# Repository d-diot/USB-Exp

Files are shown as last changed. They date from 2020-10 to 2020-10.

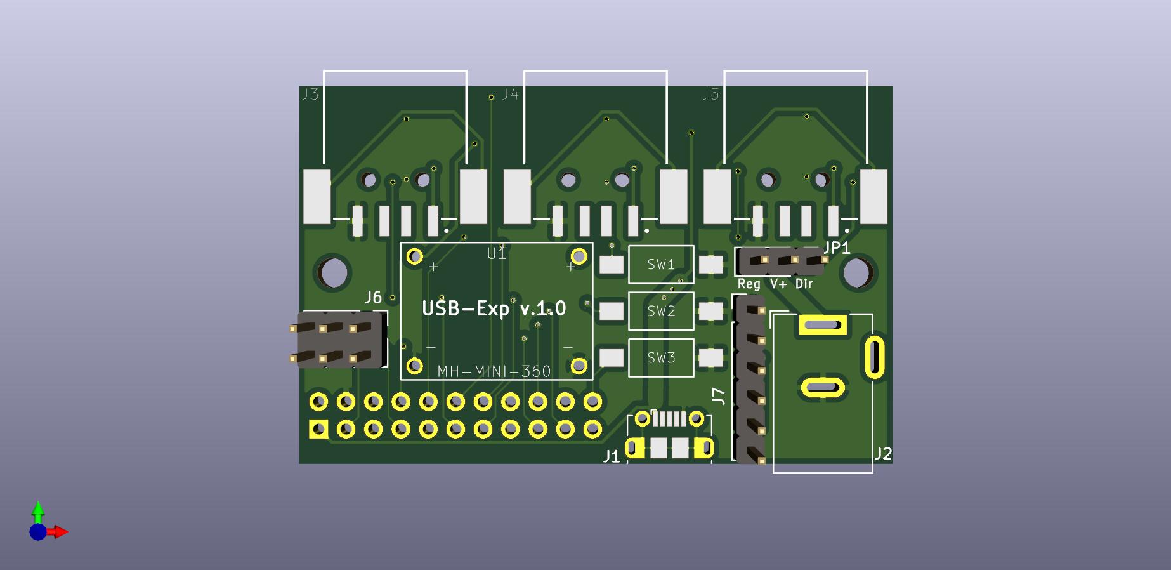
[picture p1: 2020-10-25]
export/images/1-USB-Exp-front.jpg

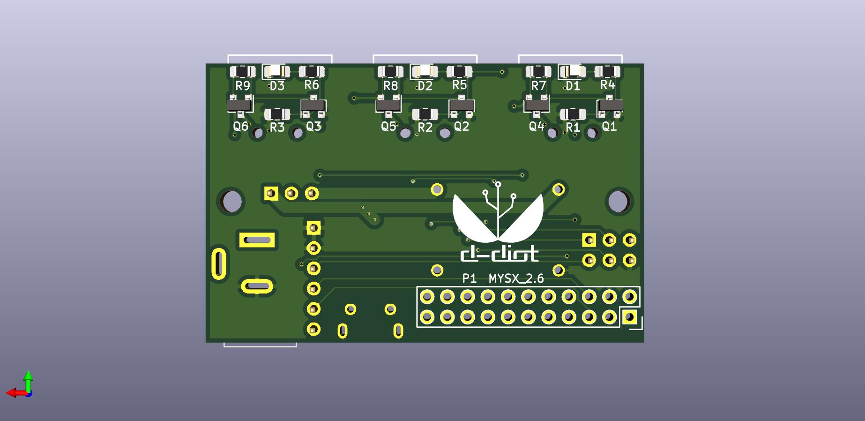
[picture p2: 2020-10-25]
export/images/2-USB-Exp-rear.jpg

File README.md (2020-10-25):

# USB-Exp

This board is part of the [d-diot project](https://www.d-diot.com)
See the dedicated [wiki page](https://wiki.d-diot.com/hardware/pcb/mysensors/usb-exp) to know more about this board.

pcbfront

pcbrear

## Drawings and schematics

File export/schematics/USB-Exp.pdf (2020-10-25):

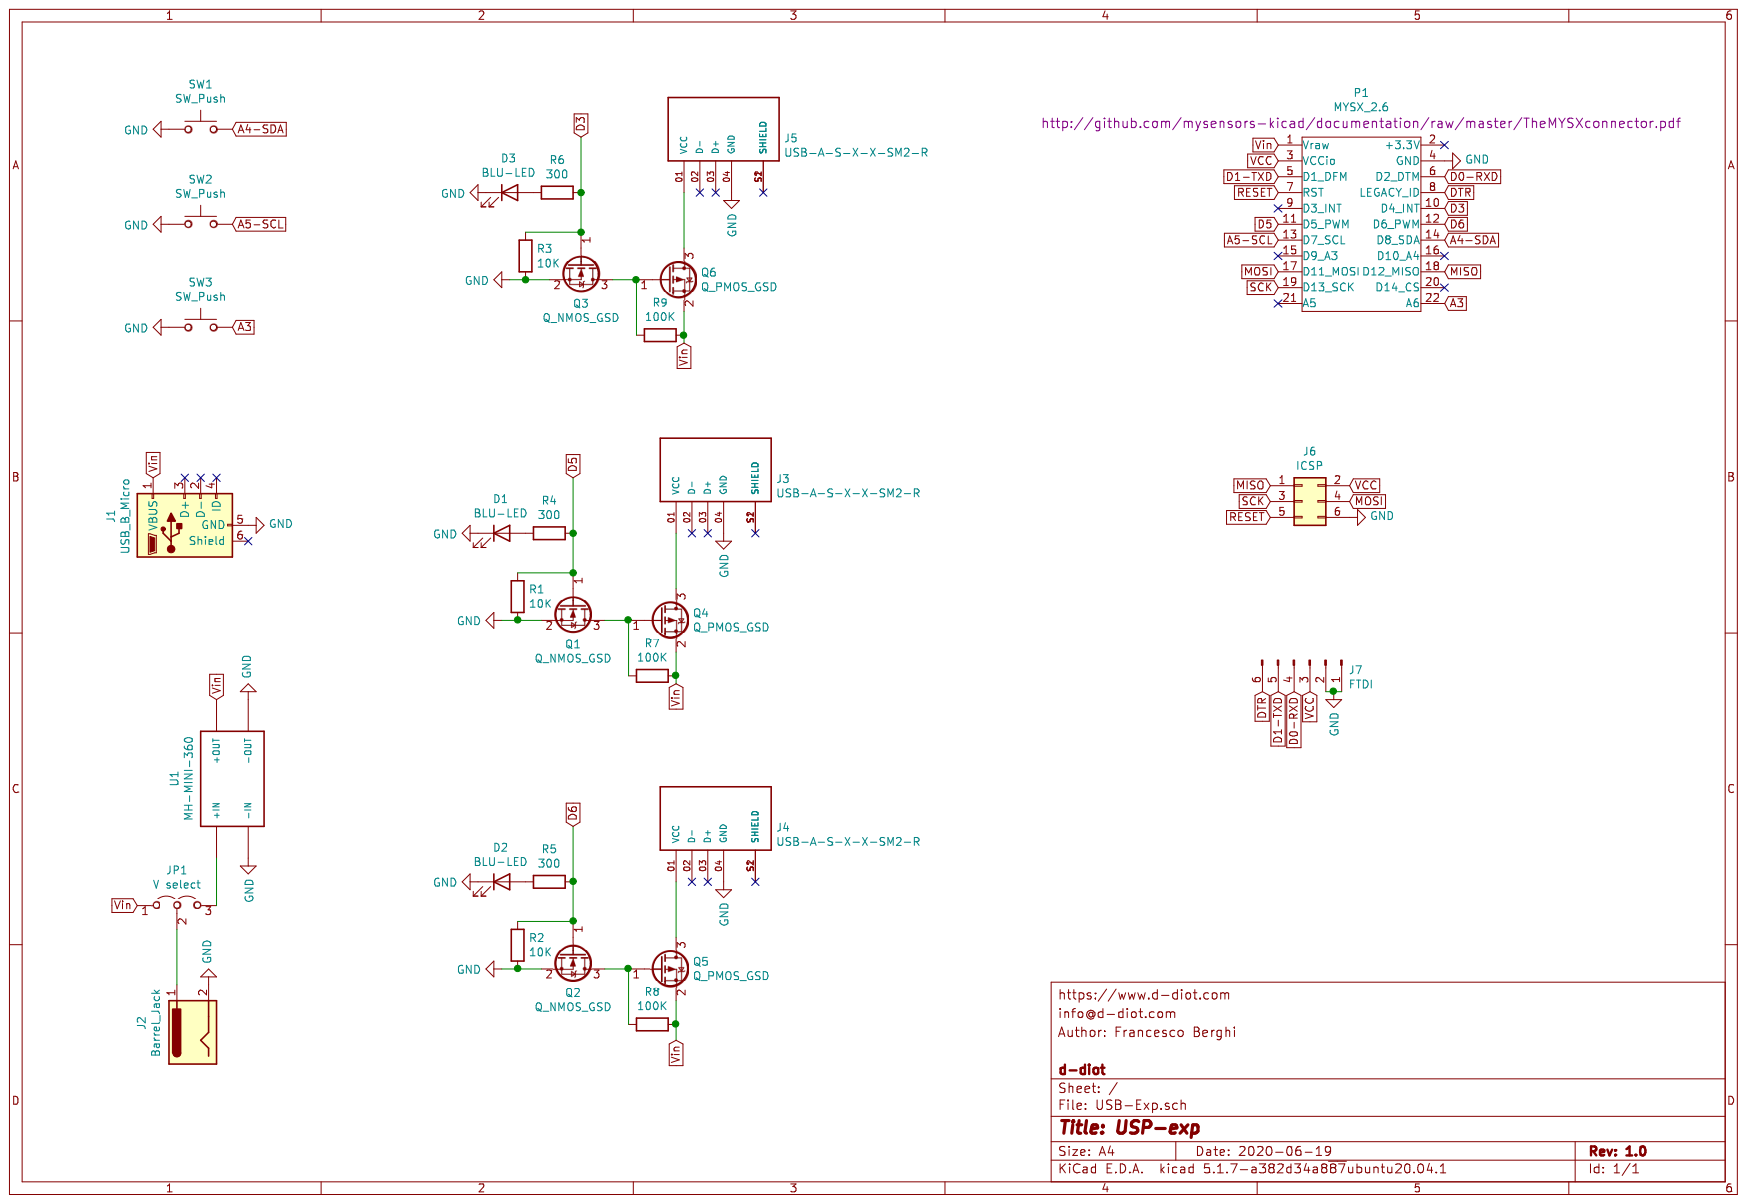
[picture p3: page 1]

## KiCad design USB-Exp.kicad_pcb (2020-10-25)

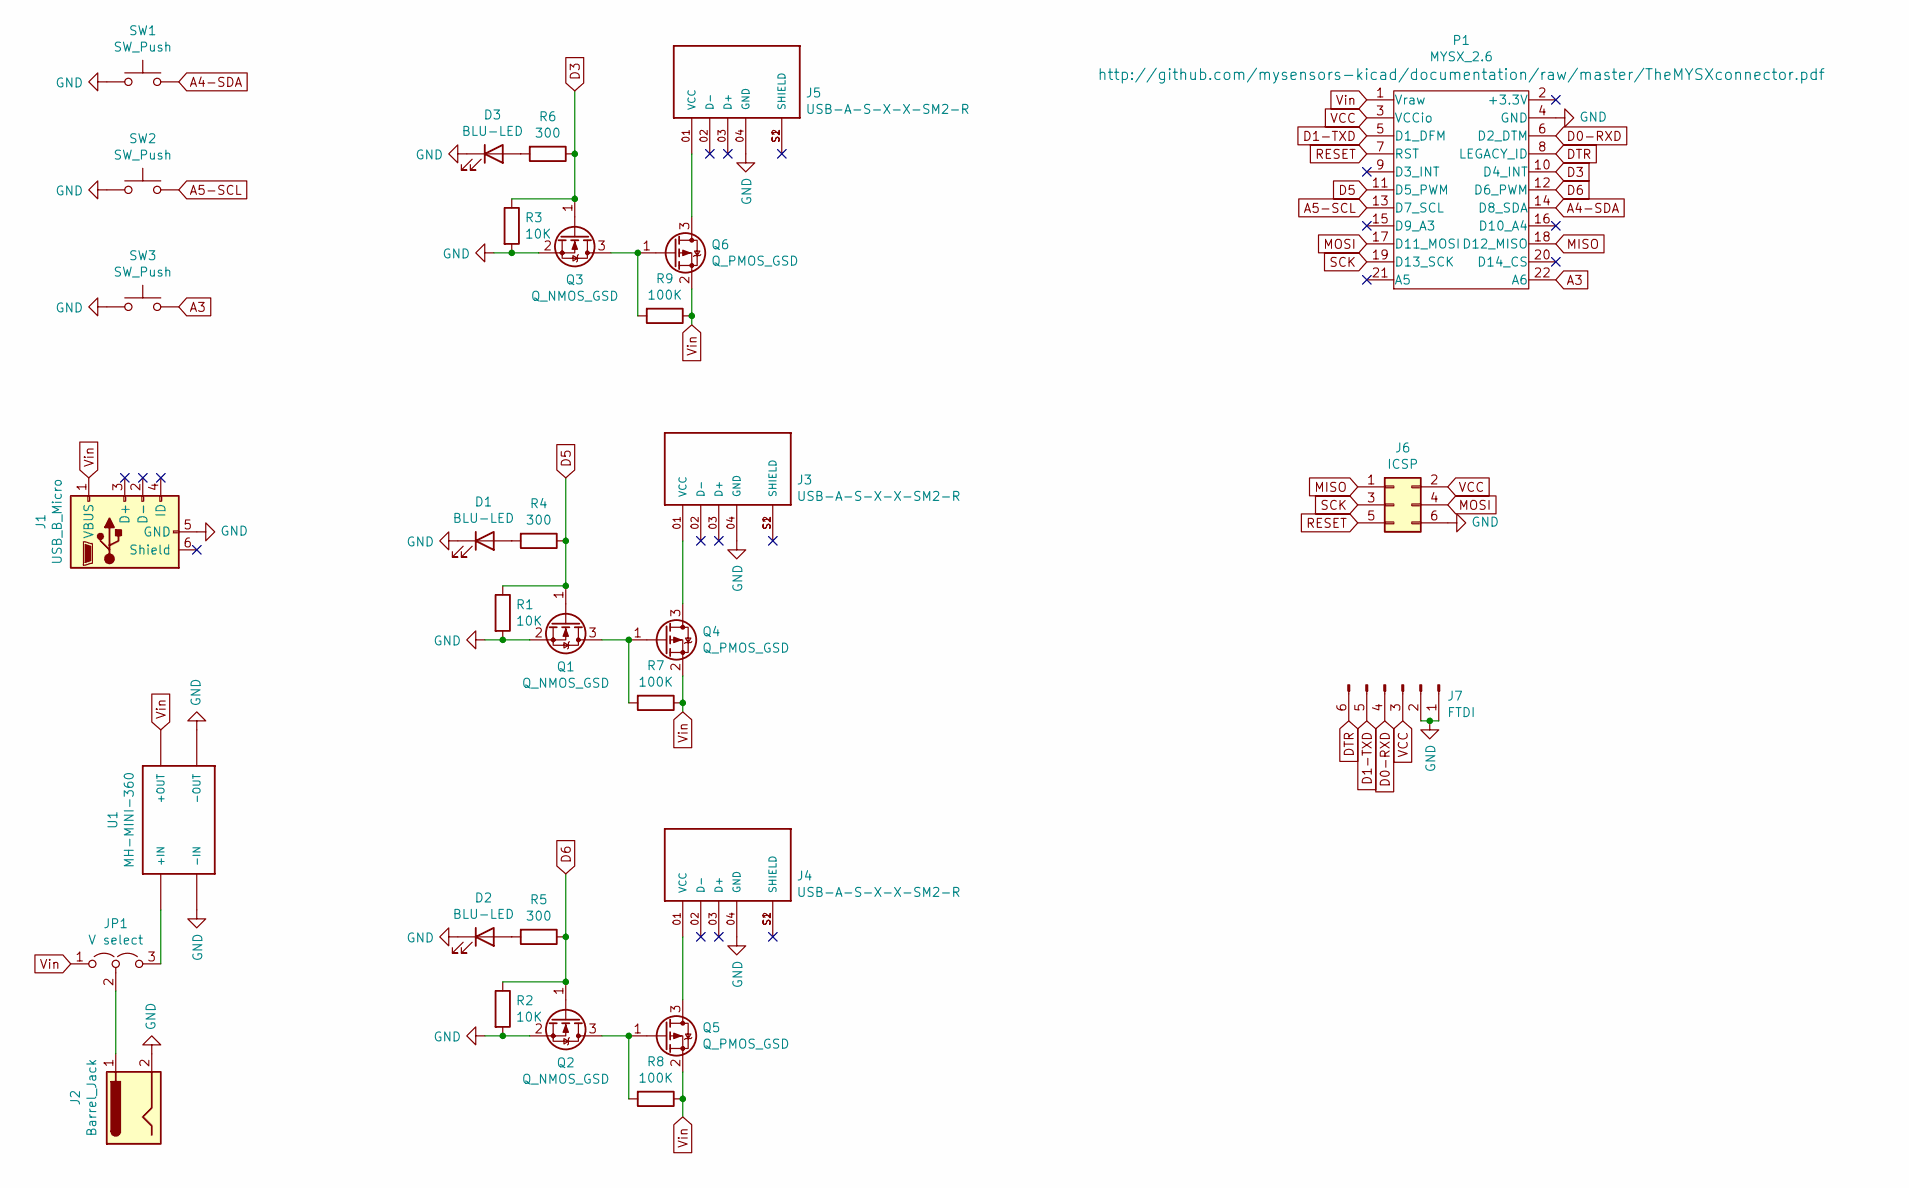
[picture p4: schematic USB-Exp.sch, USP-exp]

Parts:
D1, D2, D3: BLU-LED; LED_0805_2012Metric_Pad1.15x1.40mm_HandSolder; MPN NCD0805B2
J1: USB_B_Micro; USB_Micro-B_Molex-105017-0001; MPN C10418
J2: Barrel_Jack; BarrelJack_Wuerth_6941xx301002; MPN 694106301002
J3, J4, J5: USB-A-S-X-X-SM2-R; SAMTEC_USB-A-S-X-X-SM2-R; MPN YJ-USB-AF-SMT-01
J6: ICSP; PinHeader_2x03_P2.54mm_Vertical; MPN C65114
J7: FTDI; PinHeader_1x06_P2.54mm_Vertical; MPN Z-211-0611-0021-001
JP1: V select; PinHeader_1x03_P2.54mm_Vertical; MPN C49257
P1: MYSX_2.6; MYSX_2.6_SOCKET; MPN DS1023-2*11SF11
Q1, Q2, Q3: Q_NMOS_GSD; SOT-23; MPN JST2300
Q4, Q5, Q6: Q_PMOS_GSD; SOT-23; MPN JST3415C
R1, R2, R3: 10K; R_0805_2012Metric_Pad1.15x1.40mm_HandSolder; MPN TC0550F1002T5E
R4, R5, R6: 300; R_0805_2012Metric_Pad1.15x1.40mm_HandSolder; MPN TC0525F3000T5E
R7, R8, R9: 100K; R_0805_2012Metric_Pad1.15x1.40mm_HandSolder; MPN TC0525F1003T5E
SW1, SW2, SW3: SW_Push; SW_1437566-3; MPN NA
U1: MH-MINI-360; MPN Mini-360

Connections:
A3: P1.22 (A6), SW3.2
A4-SDA: P1.14 (D8_SDA), SW1.2
A5-SCL: P1.13 (D7_SCL), SW2.2
D0-RXD: J7.4, P1.6 (D2_DTM)
D1-TXD: J7.5, P1.5 (D1_DFM)
D3: P1.10 (D4_INT), Q3.1 (G), R3.1, R6.1
D5: P1.11 (D5_PWM), Q1.1 (G), R1.1, R4.1
D6: P1.12 (D6_PWM), Q2.1 (G), R2.1, R5.1
DTR: J7.6, P1.8 (LEGACY_ID)
GND: D1.1 (K), D2.1 (K), D3.1 (K), J1.5 (GND), J2.2, J3.04 (GND), J4.04 (GND), J5.04 (GND), J6.6, J7.1, J7.2, P1.4 (GND), Q1.2 (S), Q2.2 (S), Q3.2 (S), R1.2, R2.2, R3.2, SW1.1, SW2.1, SW3.1, U1.P$1 (-IN), U1.P$4 (-OUT)
MISO: J6.1, P1.18 (D12_MISO)
MOSI: J6.4, P1.17 (D11_MOSI)
unnamed: D1.2 (A), R4.2
unnamed: D2.2 (A), R5.2
unnamed: D3.2 (A), R6.2
unnamed: J2.1, JP1.2 (C)
unnamed: J3.01 (VCC), Q4.3 (D)
unnamed: J3.S1 (SHIELD), J3.S2 (SHIELD)
unnamed: J4.01 (VCC), Q5.3 (D)
unnamed: J4.S1 (SHIELD), J4.S2 (SHIELD)
unnamed: J5.01 (VCC), Q6.3 (D)
unnamed: J5.S1 (SHIELD), J5.S2 (SHIELD)
unnamed: JP1.3 (B), U1.P$2 (+IN)
unnamed: Q1.3 (D), Q4.1 (G), R7.2
unnamed: Q2.3 (D), Q5.1 (G), R8.2
unnamed: Q3.3 (D), Q6.1 (G), R9.2
RESET: J6.5, P1.7 (RST)
SCK: J6.3, P1.19 (D13_SCK)
VCC: J6.2, J7.3, P1.3 (VCCio)
Vin: J1.1 (VBUS), JP1.1 (A), P1.1 (Vraw), Q4.2 (S), Q5.2 (S), Q6.2 (S), R7.1, R8.1, R9.1, U1.P$3 (+OUT)

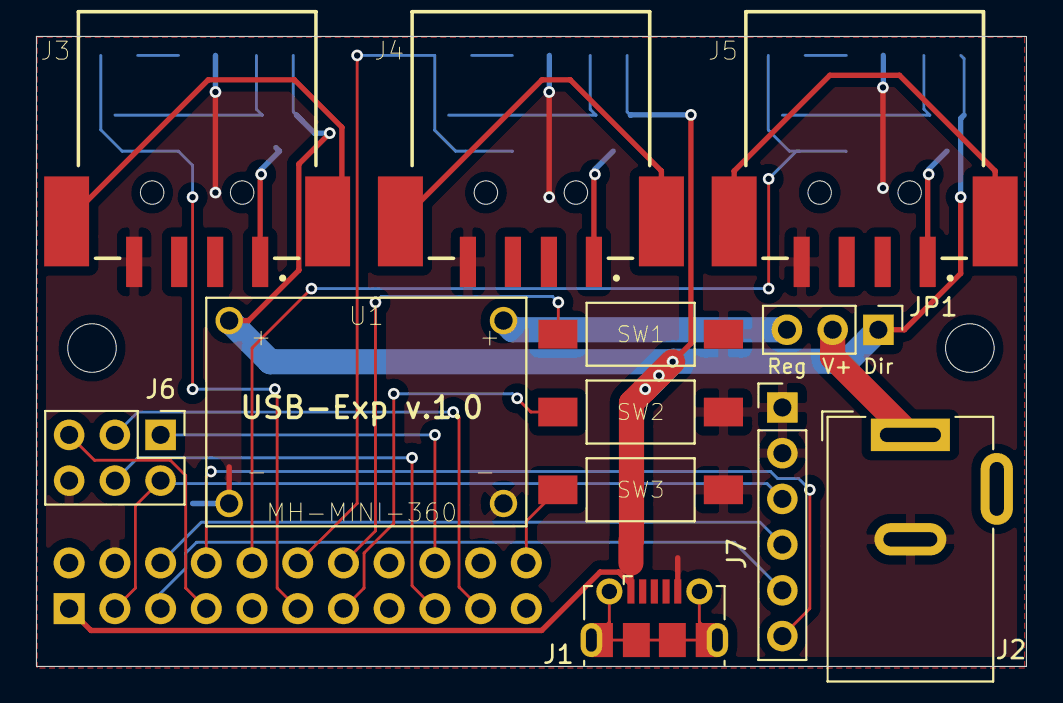
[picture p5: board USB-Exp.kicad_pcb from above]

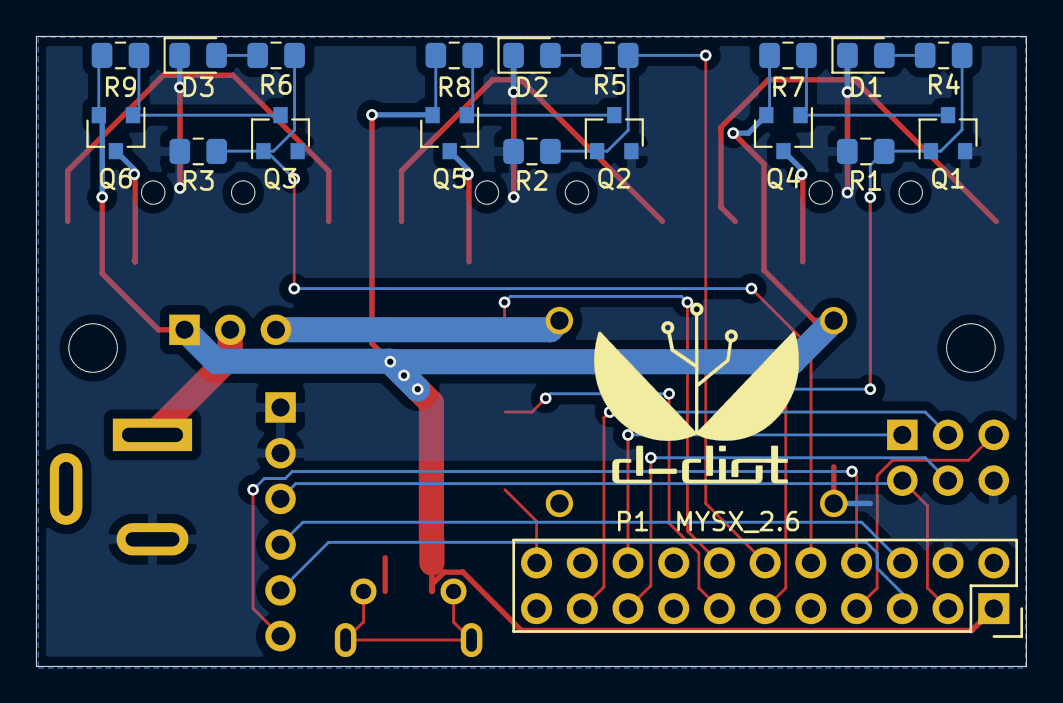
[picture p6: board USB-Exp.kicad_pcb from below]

Board: 2 copper layers, 55.0 x 35.0 mm, 31 parts (18 on the bottom side), 30 nets.

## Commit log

2020-06-20 USB-Exp first commit
    [USB-Exp-B_Cu.gbr, USB-Exp-B_Mask.gbr, USB-Exp-B_Paste.gbr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]
2020-06-22 modified gerber files and added pdf of schematics
    [USB-Exp-B_Cu.gbr, USB-Exp-B_Mask.gbr, USB-Exp-B_Paste.gbr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]
2020-07-14 fixed R, R8 and R9 connection
    [USB-Exp-B_Cu.gbl, USB-Exp-B_Mask.gbs, USB-Exp-B_Paste.gbp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]
2020-10-25 Updated documentation and README-md
    [USB-Exp.kicad_pcb, USB-Exp.sch]
